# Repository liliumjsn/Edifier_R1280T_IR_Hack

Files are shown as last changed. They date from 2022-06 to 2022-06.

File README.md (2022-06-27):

# Edifier R1280T IR Hack

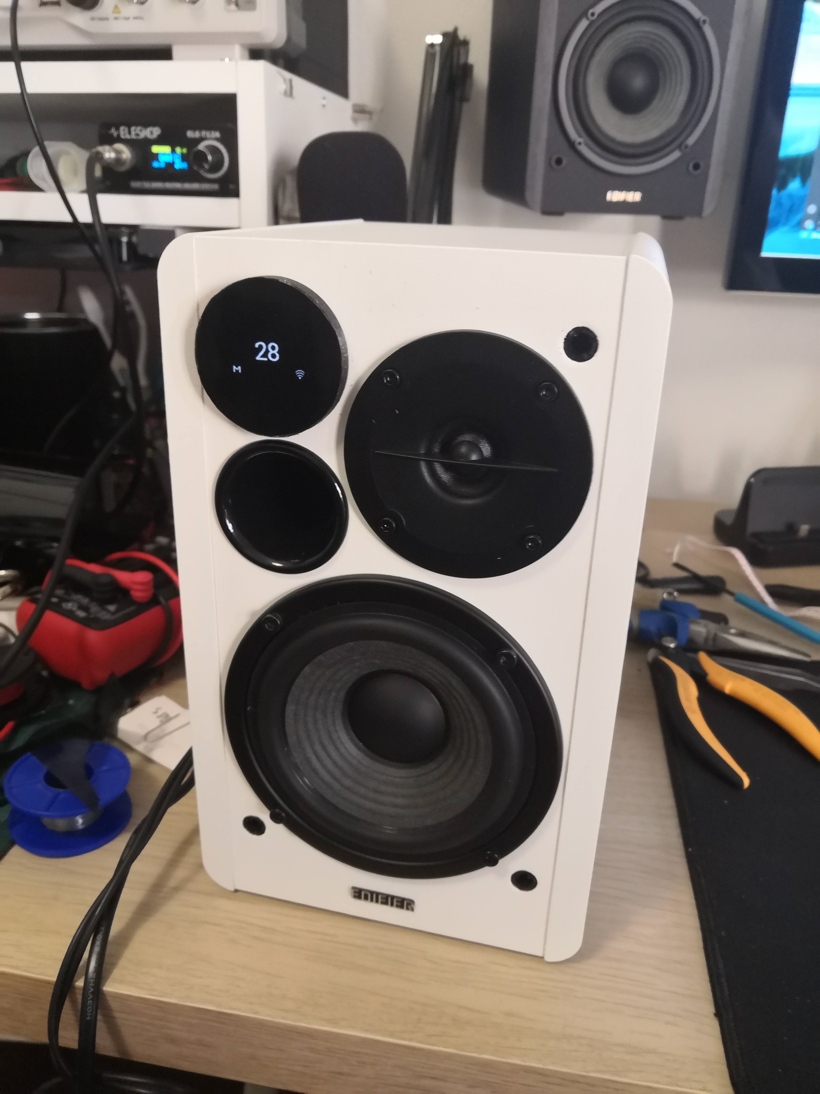
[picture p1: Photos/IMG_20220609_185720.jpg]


<p align="center">
<a href="http://www.youtube.com/watch?feature=player_embedded&v=eyL97ZMiG40
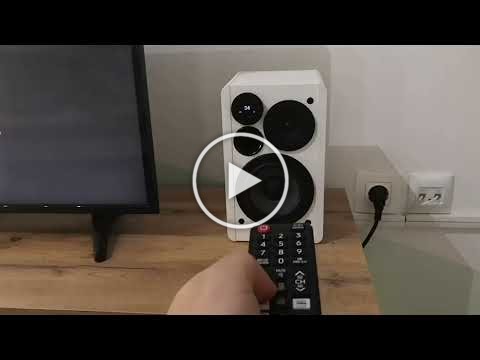
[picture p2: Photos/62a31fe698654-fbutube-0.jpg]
IMAGE ALT TEXT HERE
" target="_blank"></a>
 </p>

Modded Edifier R1280T to change volume with Samsung or any other remote. I used an esp8266 which reads the IR command, and communicates with the onboard amplifier (TAS5713) through I2C in order to change the volume. There is a black tinted OLED in front of the speaker that lights up when volume changes. The ESP is also connected to home assistant through mqtt so it can generate other commands from IR remote button presses. Source code available as a platformio project, and 3D printed parts in .3mf format.

***ATTENTION Doing this mod you will lose the knob control of the speakers and obviously your warranty.

## Comments

You will need a separate AC to 5V power supply for the ESP32 because the onboard regulators can't handle it.
Current setup supports AA,BB,CC,DD commands form the tv remote. For example command AD is a specific number,
published in mqtt topic as json:
```
Topic: home/livingroom/tvspeakers/command
{"command":13}
```

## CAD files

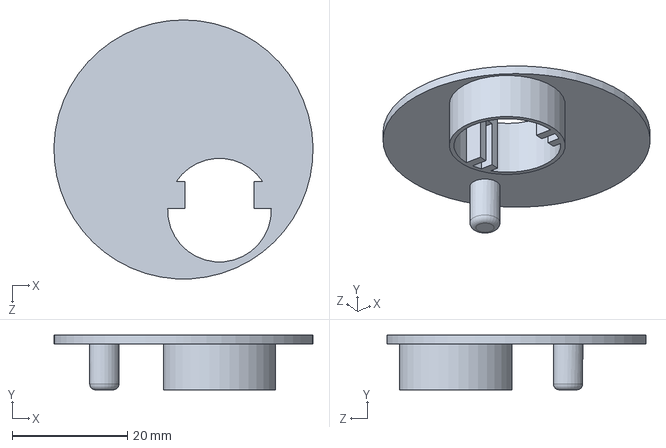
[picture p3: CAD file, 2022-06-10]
Design/PartA.SLDPRT
45.0 x 9.50 x 45.0 mm

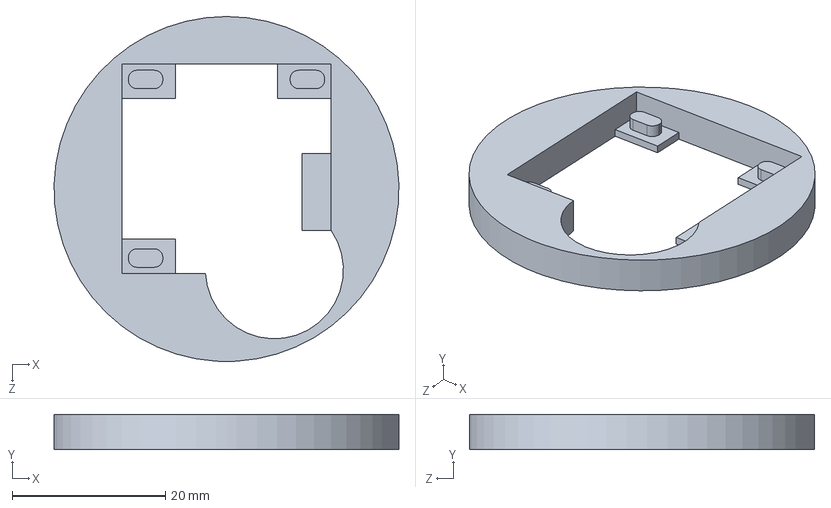
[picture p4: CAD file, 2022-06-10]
Design/PartB.SLDPRT
45.0 x 4.60 x 45.0 mm

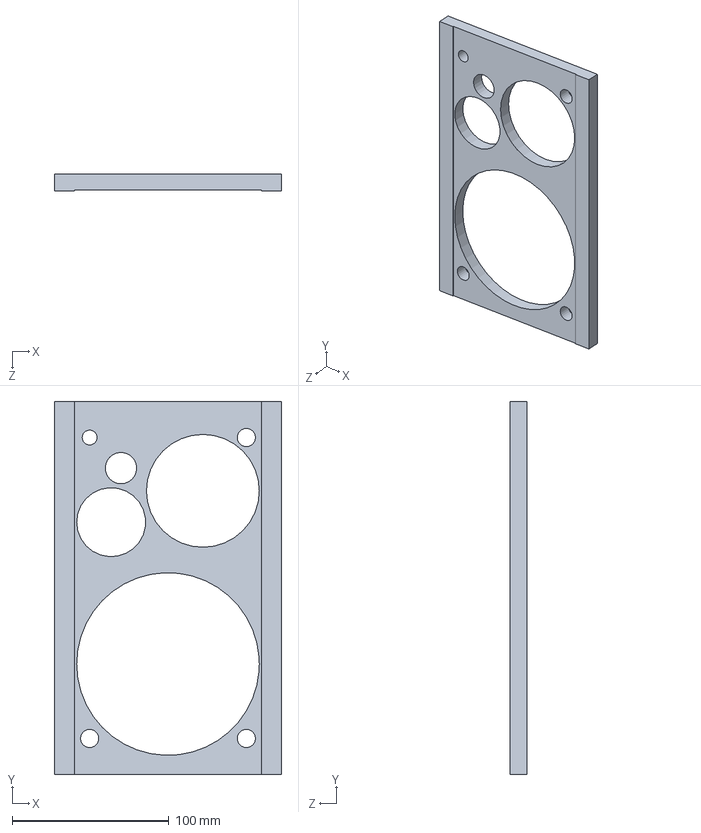
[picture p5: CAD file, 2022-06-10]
Design/Speaker.SLDPRT
145.0 x 238.0 x 10.6 mm

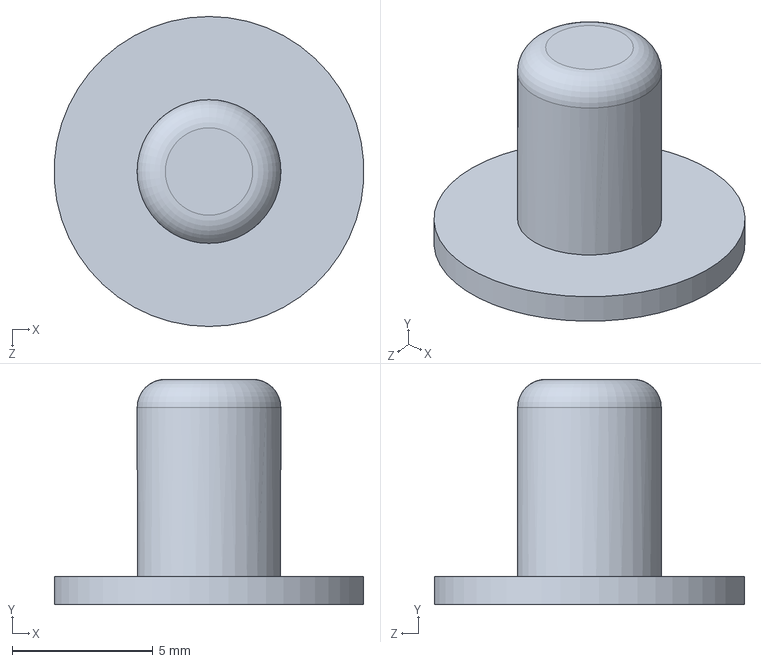
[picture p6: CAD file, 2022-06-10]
Design/PortBlock.SLDPRT
11.0 x 8.00 x 11.0 mm

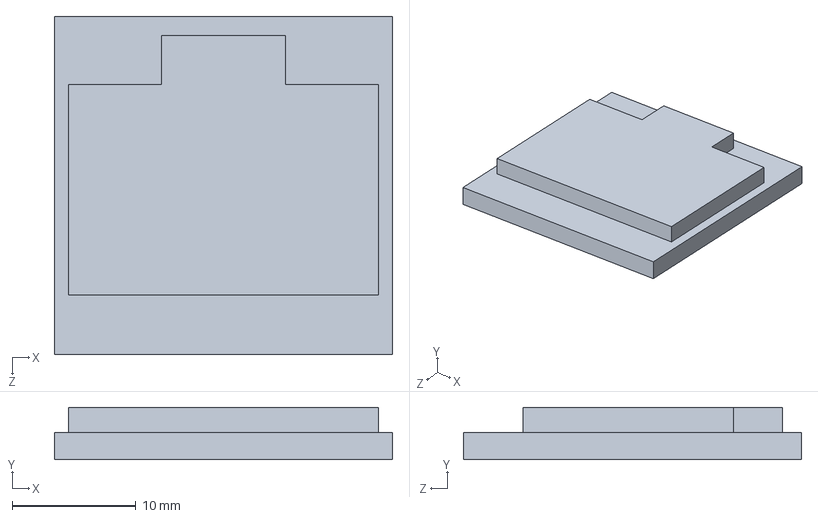
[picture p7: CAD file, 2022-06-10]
Design/oled.SLDPRT
27.3 x 4.20 x 27.3 mm

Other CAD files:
Design/PartA.3MF
Design/PartB.3MF
Design/PortBlock.3MF

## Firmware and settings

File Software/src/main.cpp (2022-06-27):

#include <Arduino.h>
#include <IRremoteESP8266.h>
#include <IRrecv.h>
#include <IRutils.h>
#include "Wire.h"
#include "EspMQTTClient.h"
#include <Ticker.h> 
#include <ArduinoJson.h>
#include "SSD1306.h"  
#include "icons.h"

SSD1306 display(0x3c, SDA, SCL);
unsigned long lastDisplayResetMillis = 0;
uint16_t displayTimeout = 5000; //millis

ICACHE_RAM_ATTR

#define AMPLIFIER_I2C_ADDRES_DEC 0x1B
#define AMPLIFIER_I2C_MV_REGISTER 0x07
#define AMPLIFIER_I2C_CH1_REGISTER 0x08
#define AMPLIFIER_I2C_CH2_REGISTER 0x09
#define MQTT_TOPIC_STATE "home/livingroom/tvspeakers/state"
#define MQTT_TOPIC_CONFIG "home/livingroom/tvspeakers/config"
#define MQTT_TOPIC_COMMAND "home/livingroom/tvspeakers/command"

#define COM_0_IR_CODE 3772790473
#define COM_1_IR_CODE 3772786903
#define COM_2_IR_CODE 3772819543
#define COM_3_IR_CODE 3772803223


uint8_t clientUpdateEveryMillis = 100;
unsigned long clientLastMillis = 0;

EspMQTTClient client(
  "xxx",
  "xxx",
  "xxx",  // MQTT Broker server ip
  "xxx",   // Can be omitted if not needed
  "xxx",   // Can be omitted if not needed
  "TVSpeakers"      // Client name that uniquely identify your device
);

Ticker publishTimer;
Ticker checkConnectionTimer;

const uint16_t kRecvPin = 13;

uint16_t autoPublishTimerSeconds = 60;
IRrecv irrecv(kRecvPin);
decode_results results;
uint8_t master_volume = 60; //-26bB
bool isMuted = false;
bool stateChanged = false;
bool isDiplayOn = true;
int8_t command = -1;
uint16_t commandTimeOut = 1000; //millis
unsigned long commandPressTS = 0;
bool showCommand;
int8_t lastCommand;
void volumeUp();
void volumeDown();
void volumeMute();
void setVolumeLevel(uint8_t);
void ampInit();
void mqttCallback(char* topic, byte* payload, unsigned int length);
void checkConnection();
void publishState();
uint8_t getVolStepSize();
void updateScreen();
uint8_t getUserVolume();
void displaySplash();
void resetDisplayTimeout();
void setDisplayBlack();
void irLoop();
void commandLoop();
void commandHandler(int8_t com);
void displayTimeoutLoop();

void setup() {  
  delay(1000);
  Serial.begin(115200);  
  Wire.begin();
  irrecv.enableIRIn();  // Start the receiver
  while (!Serial)  // Wait for the serial connection to be establised.
    delay(50);
  Serial.println("Setup begin");
  delay(200);
  if(!display.init()) Serial.println("Oled failed");
  delay(500);
  displaySplash();
  ampInit();
  delay(1200);    
  client.enableDebuggingMessages(); // Enable debugging messages sent to serial output
  client.enableHTTPWebUpdater(); // Enable the web updater. User and password default to values of MQTTUsername and MQTTPassword. These can be overridded with enableHTTPWebUpdater("user", "password").
  client.enableOTA(); // Enable OTA (Over The Air) updates. Password defaults to MQTTPassword. Port is the default OTA port. Can be overridden with enableOTA("password", port).
  client.enableLastWillMessage("TVSpeakers/lastwill", "I am going offline");  // You can activate the retain flag by setting the third parameter to true  
  delay(200);
  publishTimer.attach(autoPublishTimerSeconds, publishState);
  delay(200);  
  setVolumeLevel(master_volume);  
  Serial.println("Setup end");
}

void loop() {  
  irLoop();

  client.loop();

  commandLoop();

  displayTimeoutLoop();  
}

void onConnectionEstablished()
{
  client.subscribe(MQTT_TOPIC_CONFIG, [](const String & payload) {
    Serial.print(F("Message arrived in topic: "));  Serial.println(MQTT_TOPIC_CONFIG); 
    Serial.print(F("Message:"));
    Serial.println(payload);
    Serial.println(F("-----------------------")); 
    DynamicJsonDocument doc(256);
    deserializeJson(doc, payload);
    bool volUp = doc["volUp"];
    bool volDown = doc["volDown"];
    bool mute = doc["mute"];
    if(volUp) volumeUp();
    if(volDown) volumeDown();
    if(mute) volumeMute();
  });
}

void mqttCallback(char* topic, byte* payload, unsigned int length) {   
  Serial.print(F("Message arrived in topic: "));  Serial.println(topic); 
  Serial.print(F("Message:"));
  for (int i = 0; i < length; i++) {
    Serial.print((char)payload[i]);
  } 
  Serial.println();
  Serial.println(F("-----------------------")); 
  DynamicJsonDocument doc(256);
  deserializeJson(doc, payload);
  bool volUp = doc["volUp"];
  bool volDown = doc["volDown"];
  bool mute = doc["mute"];
  if(volUp) volumeUp();
  if(volDown) volumeDown();
  if(mute) volumeMute();
}

void publishState(){
  if(stateChanged && client.isMqttConnected()){
    stateChanged = false;
    DynamicJsonDocument doc(256);
    doc["volume"] = getUserVolume();
    doc["muted"] = isMuted;
    char jsonBuffer[256];
    serializeJson(doc, jsonBuffer);
    Serial.print(F("Publishing state:"));
    Serial.println(jsonBuffer);
    client.publish(MQTT_TOPIC_STATE, jsonBuffer); //Topic name
  }
}

void publishCommand(uint8_t com){
  DynamicJsonDocument doc(256);
  doc["command"] = com;
  char jsonBuffer[256];
  serializeJson(doc, jsonBuffer);
  Serial.print(F("Publishing command:"));
  Serial.println(jsonBuffer);
  client.publish(MQTT_TOPIC_COMMAND, jsonBuffer); //Topic name
  lastCommand = com;
  showCommand = true;
  updateScreen();  
}

void volumeUp(){  
  if(master_volume > 0) master_volume -= getVolStepSize();  
  setVolumeLevel(master_volume);
  isMuted = false;
}

void volumeDown(){  
  if(master_volume < 150) master_volume += getVolStepSize();
  if(master_volume >= 150) master_volume = 150;
  setVolumeLevel(master_volume);
  isMuted = false;  
}

void volumeMute(){
  if(isMuted){
    isMuted = false;
    setVolumeLevel(master_volume);    
  }
  else {
    isMuted = true;
    setVolumeLevel(255);
  }  
}

void ampInit(){
  Wire.beginTransmission(AMPLIFIER_I2C_ADDRES_DEC);
  Wire.write(0x1B);
  Wire.write(0x00);
  Wire.endTransmission();
  delay(100);
  Wire.beginTransmission(AMPLIFIER_I2C_ADDRES_DEC);
  Wire.write(0x05);
  Wire.write(0x00);
  Wire.endTransmission();
  delay(100);
}

void setVolumeLevel(uint8_t vol){
  Serial.print("Volume: ");
  Serial.println(getUserVolume());
  Serial.print("Mute: ");
  if(isMuted)Serial.println("ON");
  else Serial.println("OFF");
  Wire.beginTransmission(AMPLIFIER_I2C_ADDRES_DEC);
  Wire.write(AMPLIFIER_I2C_MV_REGISTER);
  Wire.write(vol);
  Wire.endTransmission();
  stateChanged = true;
  updateScreen();
}

uint8_t getVolStepSize(){
  if(master_volume > 50) return 5;
  else if(master_volume > 30) return 3;
  else if(master_volume > 15) return 2;
  else return 1;
}

void updateScreen(){  
  display.clear();
  if(isMuted){
    display.drawXbm(40, 0, 50, 50, epd_bitmap_mute_icon);
  }else if(showCommand){
    display.setFont(Roboto_40);
    display.setTextAlignment(TEXT_ALIGN_CENTER);
    display.drawString(64, 0, "#" + String(lastCommand) + "#");
    showCommand = false;
  }else{
    display.setFont(Roboto_40);
    display.setTextAlignment(TEXT_ALIGN_CENTER);
    display.drawString(64, 0, String(getUserVolume()));
  }

  if(client.isMqttConnected()) display.drawXbm(0, 49, 15, 15, epd_bitmap_mqtt_ok_icon);
  else display.drawXbm(0, 49, 15, 15, epd_bitmap_mqtt_failed_icon);

  if(client.isWifiConnected()) display.drawXbm(113, 49, 15, 15, epd_bitmap_wifi_on_icon);
  else display.drawXbm(113, 49, 15, 15, epd_bitmap_wifi_off_icon);
  // write the buffer to the display
  display.display();
  resetDisplayTimeout();
}

void displaySplash(){
  display.clear();
  display.setFont(Roboto_40);
  display.setTextAlignment(TEXT_ALIGN_CENTER);
  display.drawString(64, 0, String("JSN"));
  display.setFont(ArialMT_Plain_16);
  display.drawString(64, 40, String("Smart Speakers"));
  display.display();
  resetDisplayTimeout();
}

uint8_t getUserVolume(){
  uint8_t dv = ((150 - master_volume)/2);
  return dv;
}

void resetDisplayTimeout(){
  lastDisplayResetMillis = millis();
  isDiplayOn = true;
}

void setDisplayBlack(){
  display.clear();
  display.display();
  isDiplayOn = false;
}

void irLoop(){
  if (irrecv.decode(&results)) {
    /*
    Samsung Remote:
    Vol+: 3772833823
    Vol-: 3772829743
    Mute: 3772837903
    A: 3772790473 //COM0
    B: 3772786903 //COM1
    C: 3772819543 //COM2
    D: 3772803223 //COM3
    */         
    if(results.value == 3772833823) volumeUp();
    else if(results.value == 3772829743) volumeDown();
    else if(results.value == 3772837903) volumeMute();    

    if(results.value == COM_0_IR_CODE) commandHandler(0);
    else if(results.value == COM_1_IR_CODE) commandHandler(1);
    else if(results.value == COM_2_IR_CODE) commandHandler(2);
    else if(results.value == COM_3_IR_CODE) commandHandler(3);
    
    irrecv.resume();  // Receive the next value
  }
}

void commandHandler(int8_t com){
  if(command >=0) {
    if((unsigned long) millis() - commandPressTS > 200){
      publishCommand(10*(command+1) + com);
      commandPressTS = millis();
      command = -1;
    }    
  }
  else{
    if((unsigned long) millis() - commandPressTS > 200){
      commandPressTS = millis();
      command = com;
    }
}
}

void commandLoop(){
  if(command >=0 && (unsigned long) millis() - commandPressTS > commandTimeOut){
    publishCommand(command);
    commandPressTS = millis();
    command = -1;
  }
}

void displayTimeoutLoop(){  
  if(!isMuted && isDiplayOn && ((unsigned long) millis() - lastDisplayResetMillis > displayTimeout)){
    setDisplayBlack();
  }    
}
